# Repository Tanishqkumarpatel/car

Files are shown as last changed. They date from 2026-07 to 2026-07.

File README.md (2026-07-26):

# STM32 Autonomous Obstacle Avoidance Car

An autonomous robot car built around the **STM32 Nucleo-F446RE** microcontroller. The car uses an ultrasonic sensor to detect objects in its path and automatically navigates around them using a custom dual-motor drive system.

Robot Car Demo

## 🚀 Project Overview
This project demonstrates hardware interfacing, HAL-based timer configuration for microsecond-level precision, and custom state-machine logic in C.

The car continuously polls an HC-SR04 ultrasonic sensor using `TIM4`. Based on the returned distance, it dynamically adjusts its movement:
* **Clear Path (> 40cm):** Drives forward at full speed.
* **Caution Zone (25cm - 40cm):** Executes a custom `Roll()` function (a rapid forward/reverse pulse) to safely creep toward the object without requiring hardware PWM.
* **Obstacle Detected (< 25cm):** Halts, reverses, executes a hard right turn, and resumes forward navigation.

## 🛠️ Hardware Requirements
* **Microcontroller:** STM32 Nucleo-F446RE
* **Sensor:** HC-SR04 Ultrasonic Distance Sensor
* **Motor Driver:** TB6612FNG (Simplified module without PWM inputs)
* **Chassis:** Standard 2WD/4WD Robot Car Kit with DC Gear Motors
* **Power Supply:** 
  * 4xAAA (4.8V) Battery Pack (dedicated to driving the motors)
  * 9V Battery connected to VIN (dedicated to the Nucleo and sensor logic)

## 🔌 Pin Configuration
The GPIOs are configured via STM32CubeMX and mapped as follows:

| Component | Pin Label | STM32 Port/Pin | Function |
| :--- | :--- | :--- | :--- |
| **Driver STBY** | `A0` | `PA0` | Brings driver out of standby |
| **Right Motor (AIN1)** | `A1` | `PA1` | Right Motor Direction 1 |
| **Right Motor (AIN2)** | `A2` | `PA2` | Right Motor Direction 2 |
| **Left Motor (BIN1)** | `A3` | `PB0` | Left Motor Direction 1 |
| **Left Motor (BIN2)** | `A4` | `PC1` | Left Motor Direction 2 |
| **Sensor TRIG** | `A5` | `PC0` | Triggers 10µs ultrasonic pulse |
| **Sensor ECHO** | `D10` | `PB6` | Receives pulse (Read via `TIM4`) |

## ⚙️ Software & Setup
The project was generated using **STM32CubeMX** and developed in **STM32CubeIDE**. It utilizes the STM32 HAL (Hardware Abstraction Layer) libraries. 

To get started:
1. Clone the repository to your local machine.
   
2. Open the project in STM32CubeIDE.

3. If necessary, open the `.ioc` file to review the hardware configuration:
  * TIM4 is configured with an internal clock source, a prescaler of `83`, and a period of `65535` to provide exactly 1-microsecond tick resolution.
  * UART2 is enabled at `115200` baud to allow `printf()` to output real-time distance measurements to a serial console.

4. Build the project and flash it to the Nucleo-F446RE via the onboard ST-LINK.

## 💡 Electrical Diagram
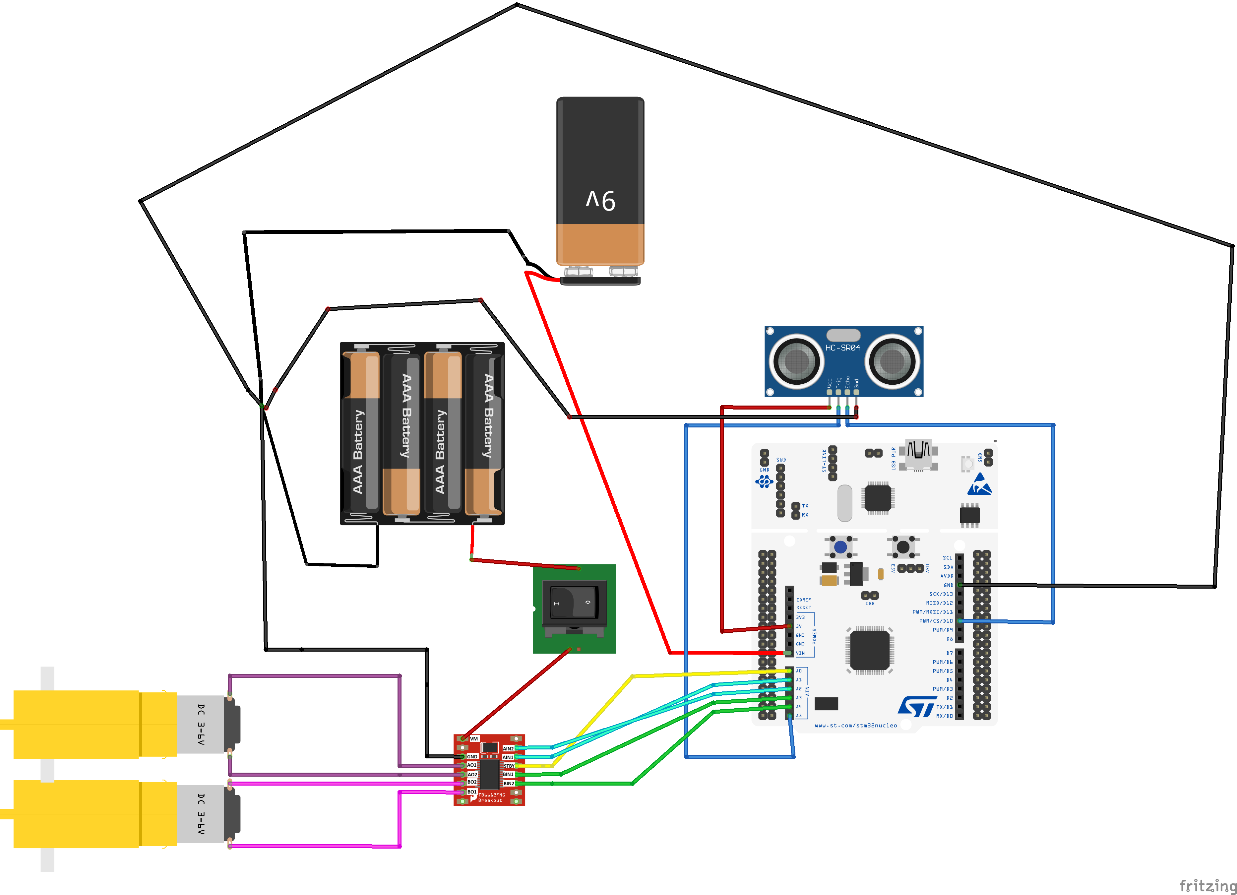
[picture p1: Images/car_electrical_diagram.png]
Car Electrical Diagram


## 📝 Key Code Highlights

* `Get_Distance()`: Calculates the distance to obstacles by manually starting/stopping `TIM4` to measure the width of the `ECHO` pulse in microseconds, including safety timeouts to prevent the microcontroller from freezing if sound waves fail to return.
* `_write()`: Retargets the standard C library so `printf()` outputs directly through the ST-LINK USB connection.

## 📸 Physical Build
<p align="center">
  
  
</p>

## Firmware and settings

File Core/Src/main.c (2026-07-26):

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
/* Includes ------------------------------------------------------------------*/
#include "main.h"

/* USER CODE BEGIN Includes */
#include <stdio.h>
/* USER CODE END Includes */

TIM_HandleTypeDef htim4;

UART_HandleTypeDef huart2;

void SystemClock_Config(void);
static void MX_GPIO_Init(void);
static void MX_USART2_UART_Init(void);
static void MX_TIM4_Init(void);
/* USER CODE BEGIN PFP */
void Forward(void);
void Back(void);
void Right(void);
void Left(void);
void Stop(void);
void Roll(void);
float Get_Distance(void);
/* USER CODE END PFP */

/**
  * @brief  The application entry point.
  * @retval int
  */
int main(void)
{

  /* MCU Configuration--------------------------------------------------------*/

  /* Reset of all peripherals, Initializes the Flash interface and the Systick. */
  HAL_Init();

  /* Configure the system clock */
  SystemClock_Config();

  /* Initialize all configured peripherals */
  MX_GPIO_Init();
  MX_USART2_UART_Init();
  MX_TIM4_Init();
  /* USER CODE BEGIN 2 */
  HAL_TIM_Base_Start(&htim4);
  HAL_GPIO_WritePin(A0_STBY_GPIO_Port, A0_STBY_Pin, GPIO_PIN_SET);
  HAL_GPIO_WritePin(GPIOA, GPIO_PIN_5, GPIO_PIN_SET);
  /* USER CODE END 2 */

  /* Infinite loop */
  /* USER CODE BEGIN WHILE */
  while (1)
  {
	  float distance = Get_Distance();
	  printf("Distance from the Object: %.2f cm\r\n", distance);

	  if (distance >=0 && distance <= 25.0) {
		  Stop();
		  HAL_Delay(200);

		  Back();
		  HAL_Delay(400);

		  Right();
		  HAL_Delay(600);

		  Stop();
		  HAL_Delay(200);
	  } else if (distance > 25.0 && distance <= 40.0) {
		  Roll();
	  } else {
		  Forward();
	  }
//	  Small Delay to prevent overlapping of sound waves.
	  HAL_Delay(50);
    /* USER CODE END WHILE */

    /* USER CODE BEGIN 3 */
  }
  /* USER CODE END 3 */
}

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
/* USER CODE BEGIN 4 */

int _write(int file, char *ptr, int len) {
    HAL_UART_Transmit(&huart2, (uint8_t*)ptr, len, HAL_MAX_DELAY);
    return len;
}


void Forward(void) {
//	Right Motor Forward
	HAL_GPIO_WritePin(A1_AIN1_RM_GPIO_Port, A1_AIN1_RM_Pin, GPIO_PIN_SET);
	HAL_GPIO_WritePin(A2_AIN2_RM_GPIO_Port, A2_AIN2_RM_Pin, GPIO_PIN_RESET);

//	Left Motor Forward
	HAL_GPIO_WritePin(A3_BIN1_LM_GPIO_Port, A3_BIN1_LM_Pin, GPIO_PIN_SET);
	HAL_GPIO_WritePin(A4_BIN2_LM_GPIO_Port, A4_BIN2_LM_Pin, GPIO_PIN_RESET);
}

void Back(void) {
//	Right Motor Reverse
	HAL_GPIO_WritePin(A1_AIN1_RM_GPIO_Port, A1_AIN1_RM_Pin, GPIO_PIN_RESET);
	HAL_GPIO_WritePin(A2_AIN2_RM_GPIO_Port, A2_AIN2_RM_Pin, GPIO_PIN_SET);

//	Left Motor Reverse
	HAL_GPIO_WritePin(A3_BIN1_LM_GPIO_Port, A3_BIN1_LM_Pin, GPIO_PIN_RESET);
	HAL_GPIO_WritePin(A4_BIN2_LM_GPIO_Port, A4_BIN2_LM_Pin, GPIO_PIN_SET);
}

void Left(void) {
//	Right Motor Forward
	HAL_GPIO_WritePin(A1_AIN1_RM_GPIO_Port, A1_AIN1_RM_Pin, GPIO_PIN_SET);
	HAL_GPIO_WritePin(A2_AIN2_RM_GPIO_Port, A2_AIN2_RM_Pin, GPIO_PIN_RESET);

//	Left Motor Reverse
	HAL_GPIO_WritePin(A3_BIN1_LM_GPIO_Port, A3_BIN1_LM_Pin, GPIO_PIN_RESET);
	HAL_GPIO_WritePin(A4_BIN2_LM_GPIO_Port, A4_BIN2_LM_Pin, GPIO_PIN_SET);

}

void Right(void) {
//	Right Motor Reverse
	HAL_GPIO_WritePin(A1_AIN1_RM_GPIO_Port, A1_AIN1_RM_Pin, GPIO_PIN_RESET);
	HAL_GPIO_WritePin(A2_AIN2_RM_GPIO_Port, A2_AIN2_RM_Pin, GPIO_PIN_SET);

//	Left Motor Forward
	HAL_GPIO_WritePin(A3_BIN1_LM_GPIO_Port, A3_BIN1_LM_Pin, GPIO_PIN_SET);
	HAL_GPIO_WritePin(A4_BIN2_LM_GPIO_Port, A4_BIN2_LM_Pin, GPIO_PIN_RESET);
}

void Stop(void) {
//	Right Motor High
	HAL_GPIO_WritePin(A1_AIN1_RM_GPIO_Port, A1_AIN1_RM_Pin, GPIO_PIN_SET);
	HAL_GPIO_WritePin(A2_AIN2_RM_GPIO_Port, A2_AIN2_RM_Pin, GPIO_PIN_SET);

//	Left Motor High
	HAL_GPIO_WritePin(A3_BIN1_LM_GPIO_Port, A3_BIN1_LM_Pin, GPIO_PIN_SET);
	HAL_GPIO_WritePin(A4_BIN2_LM_GPIO_Port, A4_BIN2_LM_Pin, GPIO_PIN_SET);
}

void Roll(void) {
	Forward();
	HAL_Delay(50);
	Back();
	HAL_Delay(10);
}

float Get_Distance(void) {
	uint32_t local_time = 0;

//	Starting the sensor
	HAL_GPIO_WritePin(A5_TRIG_GPIO_Port, A5_TRIG_Pin, GPIO_PIN_SET);

//	Waiting for timer to hit 10 micro-seconds.
	__HAL_TIM_SET_COUNTER(&htim4, 0);
	while (__HAL_TIM_GET_COUNTER(&htim4) < 10);

	HAL_GPIO_WritePin(A5_TRIG_GPIO_Port, A5_TRIG_Pin, GPIO_PIN_RESET);

//	Starting timer.
	__HAL_TIM_SET_COUNTER(&htim4, 0);

//	Checking if the Echo is high if not then graceful exit.
	while (HAL_GPIO_ReadPin(D10_ECHO_GPIO_Port, D10_ECHO_Pin) == GPIO_PIN_RESET)
	{
//		ECHO is low for 30ms. Sound waves did not fire.
		if (__HAL_TIM_GET_COUNTER(&htim4) > 30000) return -1.0;
	}

//	Reseting the timer to 0 as soon as the Sound waves are fire (ECHO is High).
	__HAL_TIM_SET_COUNTER(&htim4, 0);

//	Letting the timer runs till sound waves bounces back and is received
	while (HAL_GPIO_ReadPin(D10_ECHO_GPIO_Port, D10_ECHO_Pin) == GPIO_PIN_SET)
	{
		// Safety timeout (Did not receive any sound waves): Object is too far away (out of range)
		if (__HAL_TIM_GET_COUNTER(&htim4) > 30000) return -1.0;
	}

//	Gets the time it took sound waves to bounce back to receiver
	local_time = __HAL_TIM_GET_COUNTER(&htim4);

	return (local_time * 0.0343) / 2.0;
}
/* USER CODE END 4 */
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


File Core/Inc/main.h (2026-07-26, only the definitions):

#define B1_Pin GPIO_PIN_13
#define B1_GPIO_Port GPIOC
#define A5_TRIG_Pin GPIO_PIN_0
#define A5_TRIG_GPIO_Port GPIOC
#define A4_BIN2_LM_Pin GPIO_PIN_1
#define A4_BIN2_LM_GPIO_Port GPIOC
#define A0_STBY_Pin GPIO_PIN_0
#define A0_STBY_GPIO_Port GPIOA
#define A1_AIN1_RM_Pin GPIO_PIN_1
#define A1_AIN1_RM_GPIO_Port GPIOA
#define USART_TX_Pin GPIO_PIN_2
#define USART_TX_GPIO_Port GPIOA
#define USART_RX_Pin GPIO_PIN_3
#define USART_RX_GPIO_Port GPIOA
#define A2_AIN2_RM_Pin GPIO_PIN_4
#define A2_AIN2_RM_GPIO_Port GPIOA
#define LD2_Pin GPIO_PIN_5
#define LD2_GPIO_Port GPIOA
#define A3_BIN1_LM_Pin GPIO_PIN_0
#define A3_BIN1_LM_GPIO_Port GPIOB
#define TMS_Pin GPIO_PIN_13
#define TMS_GPIO_Port GPIOA
#define TCK_Pin GPIO_PIN_14
#define TCK_GPIO_Port GPIOA
#define SWO_Pin GPIO_PIN_3
#define SWO_GPIO_Port GPIOB
#define D10_ECHO_Pin GPIO_PIN_6
#define D10_ECHO_GPIO_Port GPIOB

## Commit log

2026-07-26 Optimize Distance And Confirm Motor drivers capabilities...
2026-07-26 Fix Bugs: Config car.ioc and fix variable names
    [car.ioc, main.c, main.h]
2026-07-26 Fix: linker for float printf
    [main.c]
2026-07-26 Add Electrical diagram
    [car.fzz]
2026-07-26 Update car_diagram: Labels the motor driver
2026-07-26 Add README for STM32 Autonomous Obstacle Avoidance Car
    Added detailed project description, hardware requirements, pin configuration, software setup, and key code highlights for the STM32 Autonomous Obstacle Avoidance Car.

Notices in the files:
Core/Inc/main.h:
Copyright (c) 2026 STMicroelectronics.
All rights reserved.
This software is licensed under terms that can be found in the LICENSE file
